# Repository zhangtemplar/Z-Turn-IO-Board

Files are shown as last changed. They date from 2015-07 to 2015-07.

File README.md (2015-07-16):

# Z-Turn-IO-Board
my own expansion board which converts the 1.27mm pitch connector to 2.54mm pitch connector for Z-turn board (http://www.myirtech.com/list.asp?id=502) from MYiR

###
A lot of design is borrowed from the IO Cape board (http://www.myirtech.com/list.asp?id=532) of MYiR, where I converts the Connector 1 to 6 PMOD compatible (2.54 mm dual row 12 pin header) headers and 1 40 pin FFC/FPC connector (for LCD); and Connector 2 to 2 PMOD headers plus 2 2.54mm dual row 34 pin header. Especially:

Connector | Comments
--------- | --------
CN1, CN2 | two 1.27mm pitch dual row 80 pin headers from Z-turn board
J1,J2|two 2.54mm pitch dual row 34 pin headers for FPGA differential pin (12 pairs each);
LCD|40 pin FFC/FPC connector;
MISC|PMOD header for I2C;
I2S|PMOD header for I2S and HDMI;
J3, J4, J5, J6|PMOD header for FPGA differential pin (4 pairs each);
ADC|PMOD header for XADC input (two pairs of analog input);
MIO|PMOD header for ARM IO pin (8 pins);
Note|the differential pins is not ready for high speed differential usage yet, as the length is not properly configured.

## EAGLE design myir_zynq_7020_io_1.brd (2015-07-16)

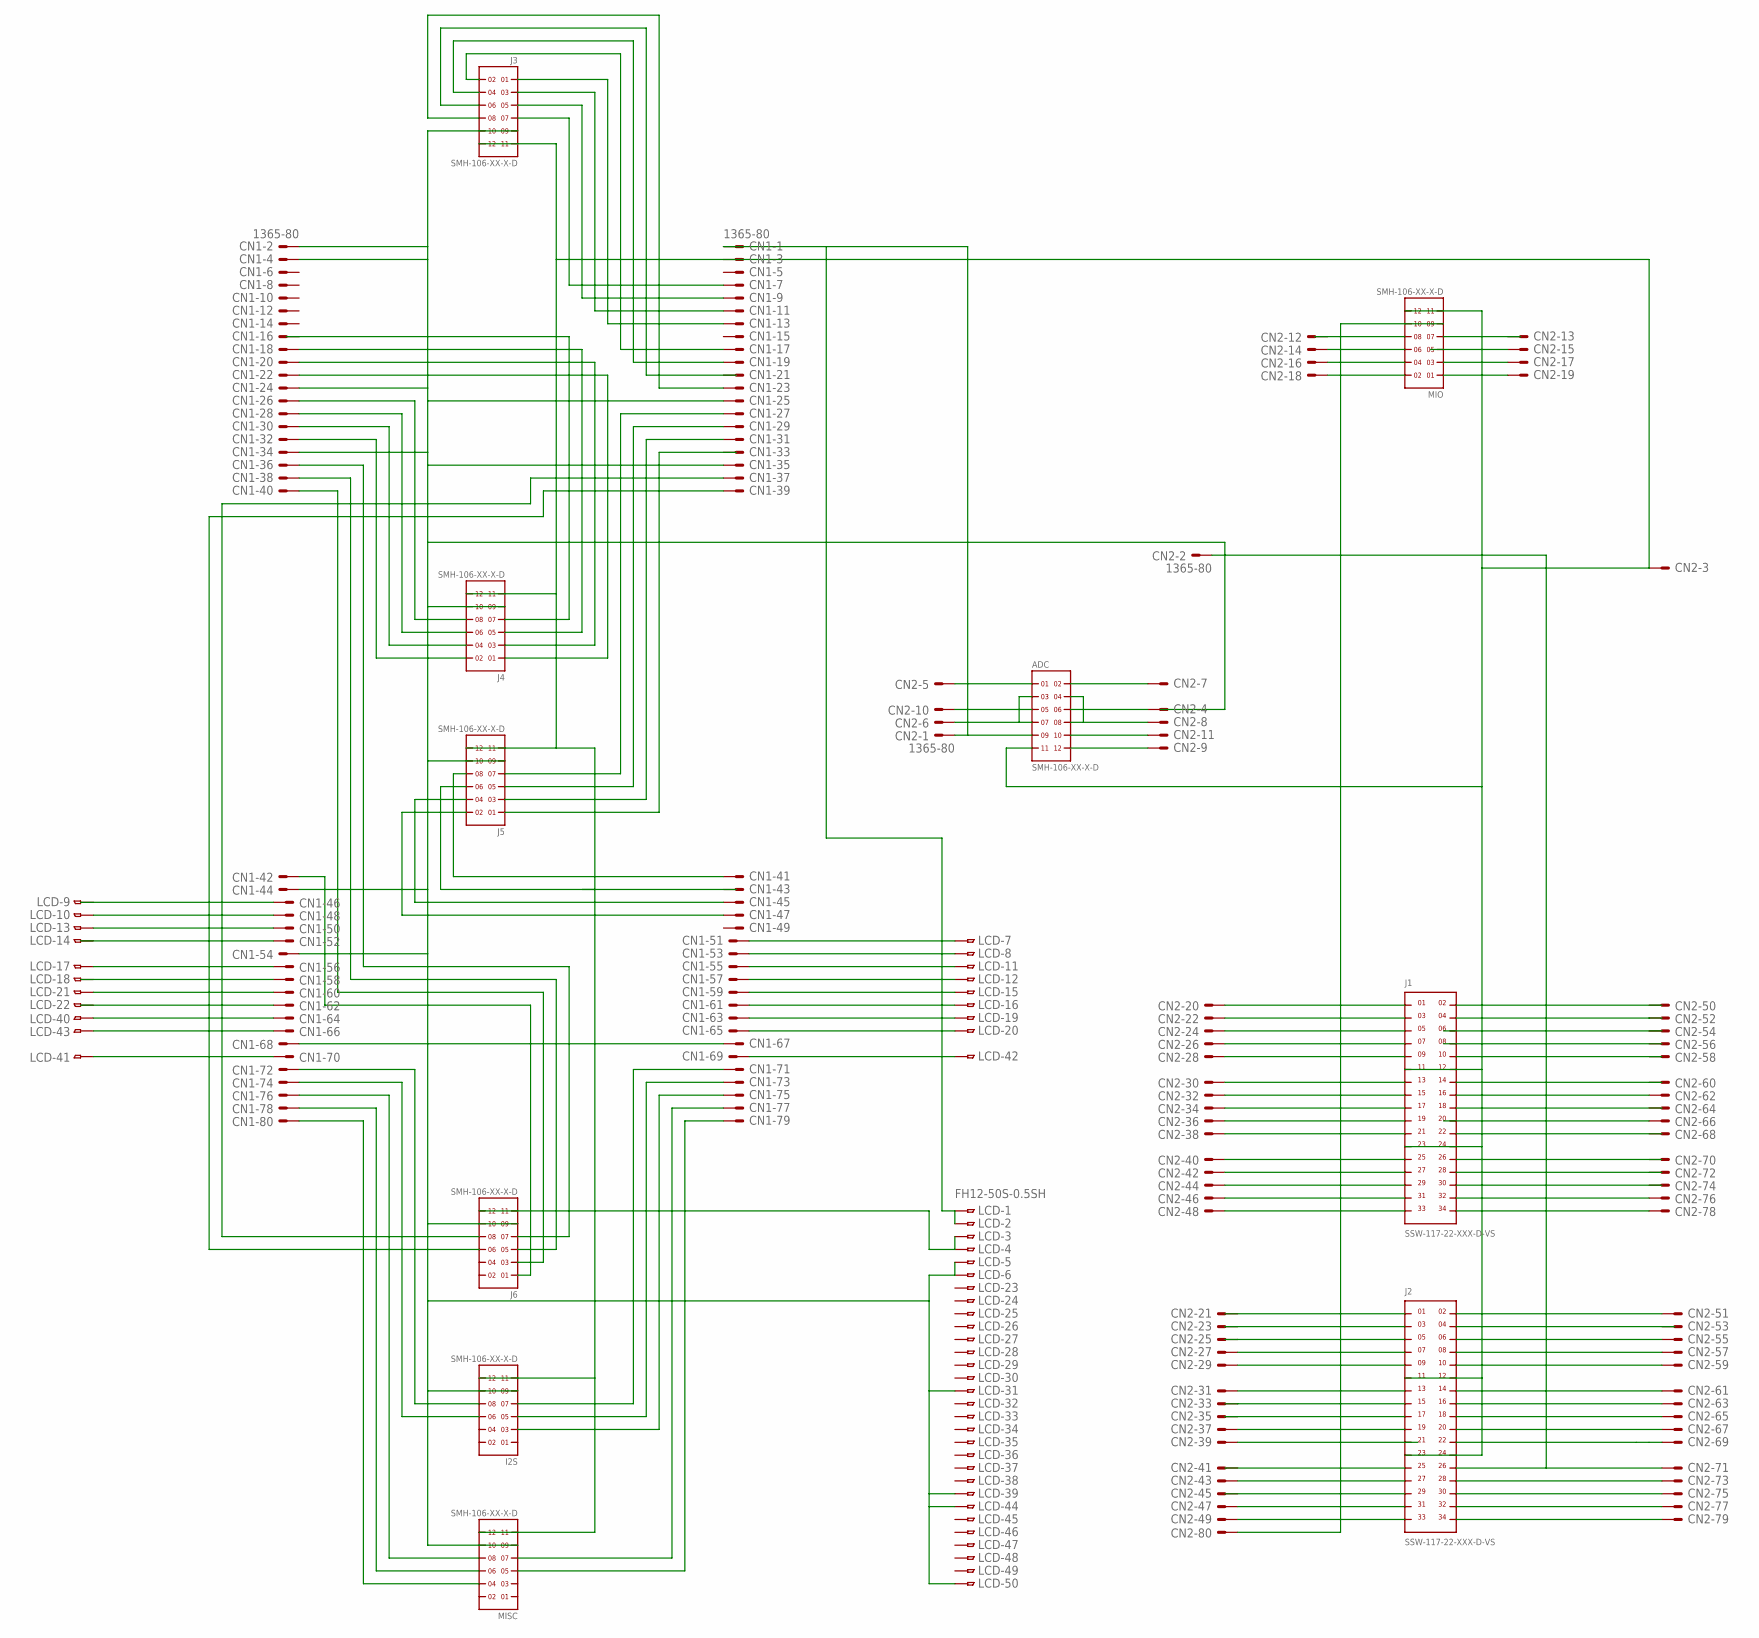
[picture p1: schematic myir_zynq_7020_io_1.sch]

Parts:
ADC: SMH-106-XX-X-D
CN1, CN2: 1365-80
I2S: SMH-106-XX-X-D
J1, J2: SSW-117-22-XXX-D-VS
J3, J4, J5, J6: SMH-106-XX-X-D
LCD: FH12-50S-0.5SH
MIO: SMH-106-XX-X-D
MISC: SMH-106-XX-X-D

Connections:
unnamed: CN1.70, LCD.41
unnamed: CN1.53, LCD.8
unnamed: CN1.66, LCD.43
unnamed: CN1.7, J3.7
unnamed: CN1.9, J3.5
unnamed: CN1.11, J3.3
unnamed: CN1.13, J3.1
unnamed: CN1.64, LCD.40
unnamed: CN1.40, J6.3
unnamed: CN1.38, J6.5
unnamed: CN1.36, J6.7
unnamed: CN1.42, J6.1
unnamed: CN1.27, J5.7
unnamed: CN1.29, J5.5
unnamed: CN1.31, J5.3
unnamed: ADC.11, CN1.3, CN2.3, I2S.11, I2S.12, J1.11, J1.12, J1.23, J1.24, J2.11, J2.12, J2.23, J2.24, J3.11, J3.12, J4.11, J4.12, J5.6, J5.11, J5.12, J6.11, J6.12, LCD.3, LCD.4, MIO.11, MIO.12, MISC.11, MISC.12
unnamed: CN1.41, J5.8
unnamed: CN1.37, J6.8
unnamed: CN1.39, J6.6
unnamed: CN1.45, J5.4
unnamed: CN1.51, LCD.7
unnamed: CN2.62, J1.16
unnamed: CN1.55, LCD.11
unnamed: CN1.71, I2S.7
unnamed: CN1.73, I2S.5
unnamed: CN1.75, I2S.3
unnamed: CN1.77, MISC.7
unnamed: CN1.79, MISC.5
unnamed: CN1.2, CN1.4, CN1.24, CN1.25, CN1.34, CN1.35, CN1.44, CN1.54, CN1.67, CN1.68, CN2.2, CN2.20, CN2.30, CN2.31, CN2.40, CN2.51, CN2.61, CN2.71, CN2.80, I2S.9, I2S.10, J1.1, J1.2, J1.13, J1.14, J1.25, J1.26, J2.1, J2.2, J2.13, J2.14, J2.25, J2.26, J3.9, J3.10, J4.9, J4.10, J5.9, J5.10, J6.9, J6.10, LCD.5, LCD.6, LCD.31, LCD.39, LCD.44, LCD.50, MIO.9, MIO.10, MISC.9, MISC.10
unnamed: CN1.57, LCD.12
unnamed: CN2.76, J1.32
unnamed: CN2.69, J2.22
unnamed: CN2.67, J2.20
unnamed: CN2.65, J2.18
unnamed: CN2.63, J2.16
unnamed: CN1.16, J4.7
unnamed: CN1.18, J4.5
unnamed: CN1.20, J4.3
unnamed: CN1.17, J3.2
unnamed: CN1.59, LCD.15
unnamed: CN1.26, J4.8
unnamed: CN1.28, J4.6
unnamed: CN1.30, J4.4
unnamed: CN1.61, LCD.16
unnamed: CN1.32, J4.2
unnamed: CN1.63, LCD.19
unnamed: CN1.65, LCD.20
unnamed: CN2.18, MIO.2
unnamed: CN2.59, J2.10
unnamed: CN2.57, J2.8
unnamed: CN2.55, J2.6
unnamed: CN2.16, MIO.4
unnamed: CN2.78, J1.34
unnamed: CN2.22, J1.3
unnamed: CN2.24, J1.5
unnamed: CN2.26, J1.7
unnamed: CN1.48, LCD.10
unnamed: CN2.28, J1.9
unnamed: CN1.72, I2S.8
unnamed: CN1.74, I2S.6
unnamed: CN1.76, MISC.8
unnamed: CN1.78, MISC.6
unnamed: CN1.80, MISC.4
unnamed: CN2.14, MIO.6
unnamed: CN2.17, MIO.3
unnamed: CN2.19, MIO.1
unnamed: CN2.27, J2.7
unnamed: ADC.12, CN2.9
unnamed: CN2.29, J2.9
unnamed: ADC.2, CN2.7
unnamed: CN2.32, J1.15
unnamed: CN2.34, J1.17
unnamed: CN2.36, J1.19
unnamed: CN2.38, J1.21
unnamed: ADC.1, CN2.5
unnamed: ADC.10, CN2.11
unnamed: CN2.25, J2.5
unnamed: CN2.37, J2.19
unnamed: ADC.4, ADC.8, CN2.8
unnamed: CN2.43, J2.27
unnamed: CN2.47, J2.31
unnamed: CN2.49, J2.33
unnamed: ADC.3, ADC.7, CN2.6
unnamed: CN2.33, J2.15
unnamed: ADC.5, CN2.10
unnamed: ADC.6, CN2.4
unnamed: CN1.47, J5.2
unnamed: CN1.22, J4.1
unnamed: CN1.19, J3.4
unnamed: CN2.73, J2.28
unnamed: CN2.75, J2.30
unnamed: CN2.77, J2.32
unnamed: CN2.79, J2.34
unnamed: CN1.23, J3.8
unnamed: CN2.52, J1.4
unnamed: CN1.50, LCD.13
unnamed: CN1.56, LCD.17
unnamed: CN1.60, LCD.21
unnamed: ADC.9, CN1.1, CN2.1, LCD.1, LCD.2
unnamed: CN1.69, LCD.42

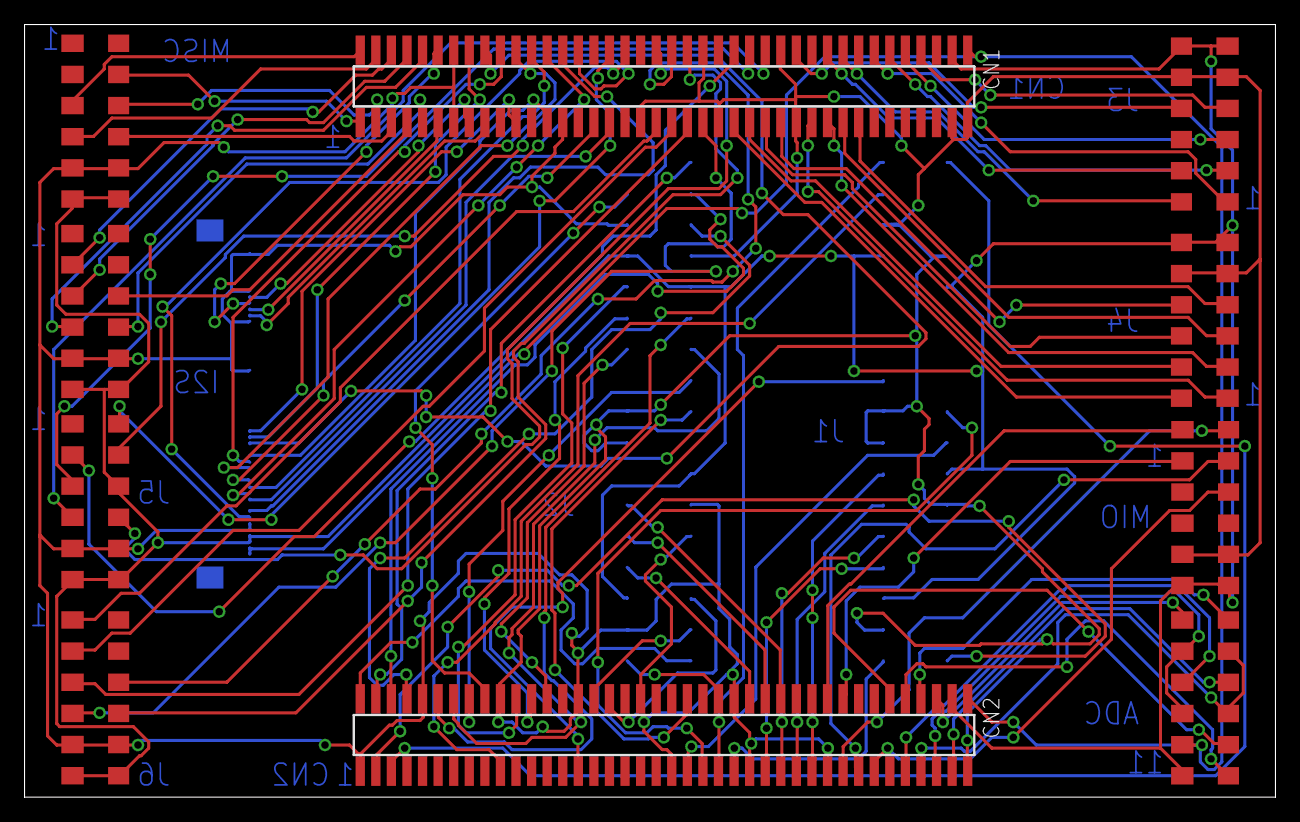
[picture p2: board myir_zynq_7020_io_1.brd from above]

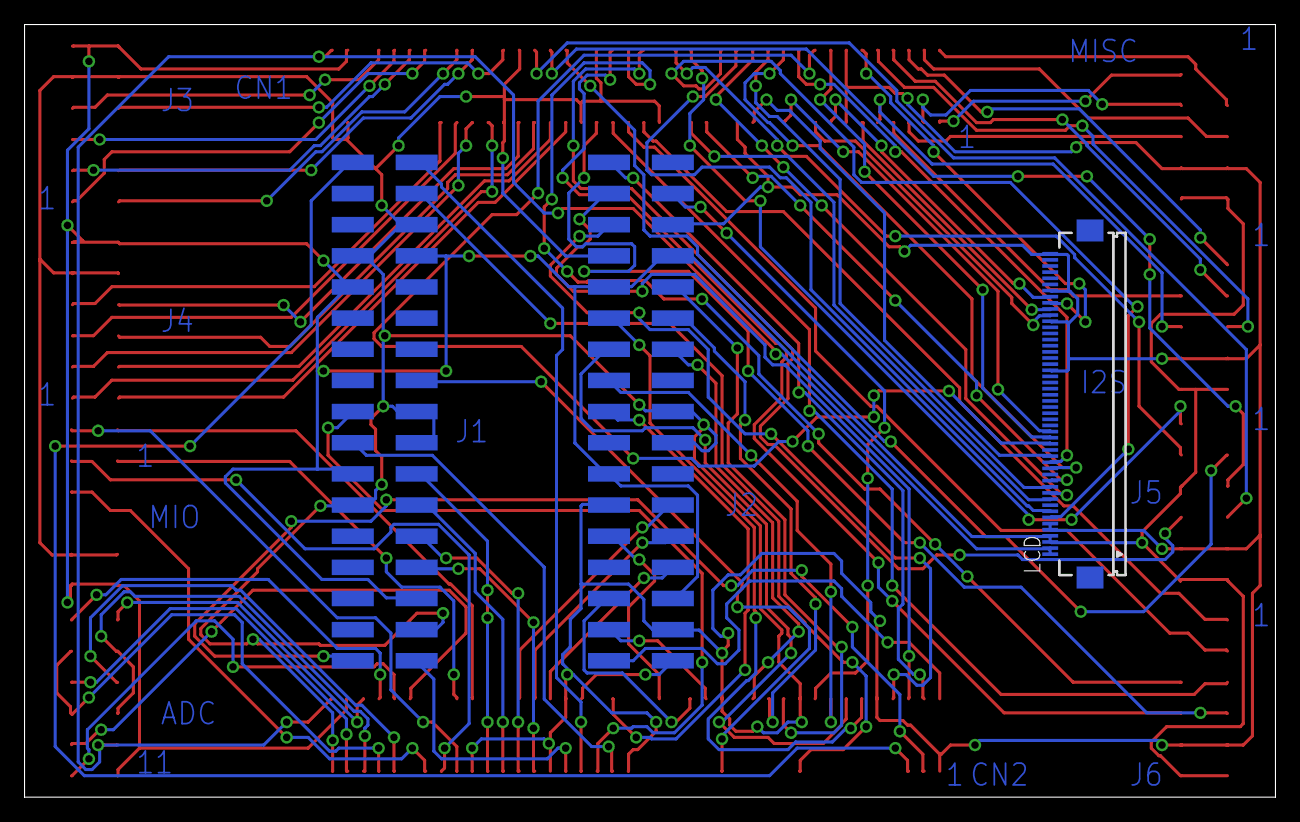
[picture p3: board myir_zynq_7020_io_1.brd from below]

Board: 2 copper layers, 102.0 x 63.0 mm, 13 parts (3 on the bottom side), 100 nets.
